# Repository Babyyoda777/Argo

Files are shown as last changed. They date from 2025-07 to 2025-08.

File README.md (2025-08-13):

# Argo









## Mainboard
The main board houses the CM5 and breaks out the most basic functionality needed.

- 2x 100pin Hirose Connectors
- 2x MIPI-DSI/CSI
- 1x Micro-HDMI
- 1x HDMI FPC connector for external break out
- 1x PCIe FPC connector, Pi 5 compatible
- 2x USB-C (One for power/flashing - USB 2.0 and one regular USB 3.0)
- Integrated BMS (BQ25895) with up to 15W output dependent on battery used.
- I2C control for BQ25895

Read more about the mainboard [here](./mainboard.md)

## Expansion Boards:

### M.2 PCIe Expansion:
- Adds an M.2 M-Key Slot for external SSD
Read more about the SSD board [here](./ssdboard.md)

### Impedance Calculations:



### OSHWA Certification:

PNG image

## Sponsored by OSHWLab Stars and HackClub:
 &nbsp;

 &nbsp;
  &nbsp;
   &nbsp;

 &nbsp;
  &nbsp;
   &nbsp;


Huge thanks to Bob from OSHWLab for all the support and sponsoring the PCBA! If you're a teenager interested in tech, checkout [HackClub](https://hackclub.com), huge thanks to them for covering remaining tools/materials costs.

### BOM:

| Part | Quantity | Price |
|---|---|---|
| Mainboard PCBA | 5 | $0.00  Paid Myself |
| SSD PCBA | 3 | $0.00 Paid myself funds redirected to soldering iron + batteries and jumper cables |
| Shipping + Taxes | 1 | $57.80 |
| [3.7V 3000mAh LiPo](https://www.aliexpress.com/item/1005006866132237.html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) | 1 | $25.00 |
| Thermal Pads | 1x | $8 |
| Raspberry Pi CM5 | | $120.00 |
| CM5 Cooler | 1 | $7.00 |
| PCIe FPC + Display FPC | 3 | $3.95 |
| Soldering iron + solder + microsoldering tips | 1 | $69 |
Note: Got sponsorship for PCB so price reduced to $61 from $350. 16GB CM5 needed due to the astro-stacking software and various other things that will be run in parallel.

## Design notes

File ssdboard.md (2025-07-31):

SSD Board in Argo footprint.
Support M.2 2230 and 2242 sizes NVMe SSDs. Based on offical CM5 M.2 HAT+

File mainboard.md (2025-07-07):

# Mainboard Specifications:

The mainboard is a 6 Layer 1.6mm PCB and uses the JLCPCB JLC06161H-3313 stackup. The layer distribution used is: [SIG/PWR : GND : SIG/PWR : PWR(5V) : GND : SIG/PWR]

## Layer 1 (Top):
Layer 1

## Layer 2:
Layer 2

## Layer 3:
Layer 3

## Layer 4:
Layer 4

## Layer 5:
Layer 5

## Layer 6 (Bottom):
Layer 6

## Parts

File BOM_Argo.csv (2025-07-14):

ID | Name | Designator | Footprint | Quantity | Manufacturer Part | Manufacturer | Supplier | Supplier Part
1 | CONN-SMD_DF40HC-3.0-100DS-0.4V-51 | CN1,CN2 | CONN-SMD_DF40HC-3.0-100DS-0.4V-51 | 2 | CONN-SMD_DF40HC-3.0-100DS-0.4V-51 | HRS(广濑) | LCSC | C424649
2 | GREEN | U14 | LED0603-FD | 1 | GREEN | YONGYUTAI(永裕泰) | LCSC | C19273151
3 | 1kΩ | R29,R34 | R0402 | 2 | 0402WGF1001TCE | UNI-ROYAL(厚声) | LCSC | C11702
4 | GT-TC018A-H0375-L1 | SW1 | SW-SMD_L4.7-W3.5-P3.35-EH | 1 | GT-TC018A-H0375-L1 | G-Switch(品赞) | LCSC | C963235
5 | 74LVC1G07SE-7 | U16 | SC-88A_L2.0-W1.3-P0.65-LS2.1-BL | 1 | 74LVC1G07SE-7 | DIODES(美台) | LCSC | C67531
6 | YLED0603R | LED1 | LED0603-FD | 1 | YLED0603R | YONGYUTAI(永裕泰) | LCSC | C19171390
7 | TS-1928-B | SW2 | KEY-SMD_4P-L2.8-W2.0-P1.20-LS3.0-TL | 1 | TS-1928-B | XKB Connectivity(中国星坤) | LCSC | C1121891
8 | BQ25895RTWR | U9 | QFN-24_L4.0-W4.0-P0.50-TL-EP2.7 | 1 | BQ25895RTWR | TI(德州仪器) | LCSC | C80200
9 | 2.2uH | L1 | IND-SMD_L6.5-W6.5_IHLP-2525 | 1 | IHLP2525CZER2R2M01 | VISHAY(威世) | LCSC | C540967
10 | 47nF | C4 | C0402 | 1 | CC0402KRX7R8BB473 | YAGEO(国巨) | LCSC | C107020
11 | 4.7uF | C3,C59 | C0603 | 2 | CL10A475KO8NNNC | SAMSUNG(三星) | LCSC | C19666
12 | 1uF | C1,C58 | C0805 | 2 | CL21B105KBFNNNE | SAMSUNG(三星) | LCSC | C28323
13 | 10kΩ | R13,R14,R15,R16,R26,R27,R28 | R0402 | 7 | 0402WGF1002TCE | UNI-ROYAL(厚声) | LCSC | C25744
14 | 10uF | C2,C5,C31,C51,C52 | C0805 | 5 | GRM21BR71A106KE51L | muRata(村田) | LCSC | C86038
15 | TYPEC-304J-BCP16 | PWR | USB-C-SMD_TYPEC-304J-BCP16 | 1 | TYPEC-304J-BCP16 | XUNPU(讯普) | LCSC | C2835315
16 | 5.1kΩ | R7,R6 | R0603 | 2 | 0603WAF5101T5E | UNI-ROYAL(厚声) | LCSC | C23186
17 | NSR10F20NXT5G | D1 | DSN-2_L1.4-W0.6-RD | 1 | NSR10F20NXT5G | onsemi(安森美) | LCSC | C893809
18 | 22uF | C55,C56,C57 | C0805 | 3 | CL21A226MAQNNNE | SAMSUNG(三星) | LCSC | C45783
19 | TLV70430DBVR | U13 | TSOT-23-5_L2.9-W1.6-P0.95-LS2.8-BR | 1 | TLV70430DBVR | TI(德州仪器) | LCSC | C133625
20 | BAT54C-7-F | D2 | SOT-23-3_L2.9-W1.6-P1.90-LS2.8-BR | 1 | BAT54C-7-F | DIODES(美台) | LCSC | C134405
21 | 5050060812 | CN5 | CONN-SMD_5050060810 | 1 | 5050060812 | MOLEX | LCSC | C779875
22 | FH12-22S-0.5SH(55) | DPHY1,DPHY2 | FPC-SMD_22P-P0.50_FH12-22S-0.5SH-55 | 2 | FH12-22S-0.5SH(55) | HRS(广濑) | LCSC | C597981
23 | 2.2kΩ | R30,R31,R32 | R0402 | 3 | 0402WGF2201TCE | UNI-ROYAL(厚声) | LCSC | C25879
24 | GT-F0509SR15-16SMT01 | PCIe | CONN-SMD_GT-F0509SR15-16SMT01 | 1 | GT-F0509SR15-16SMT01 | G-Switch(品赞) | LCSC | C21882325
25 | RT9742GGJ5 | U7,U11 | TSOT-23-5_L2.9-W1.6-P0.95-LS2.8-BR | 2 | RT9742GGJ5 | RICHTEK(立锜) | LCSC | C250547
26 | 12kΩ | R12 | R0603 | 1 | 0603WAF1202T5E | UNI-ROYAL(厚声) | LCSC | C22790
27 | 10uF | C30 | C0805 | 1 | CL21A106KAYNNNE | SAMSUNG(三星) | LCSC | C15850
28 | 100nF | C40,C41,C62 | C0402 | 3 | CC0402KRX5R8BB104 | YAGEO(国巨) | LCSC | C106256
29 | HDMI-101W | HDMI1 | HDMI-SMD_HDMI-101W | 1 | HDMI-101W | XUNPU(讯普) | LCSC | C720619
30 | TF-123-ARP9H15 | SD-CARD | TF-SMD_TF-123-ARP9H15 | 1 | TF-123-ARP9H15 | XUNPU(讯普) | LCSC | C2982547
31 | HDGC0802WV-S-10P | SPI | CONN-SMD_10P-P0.80_HDGC0802WV-S-10P | 1 | HDGC0802WV-S-10P | HDGC(华德共创) | LCSC | C3008688
32 | BM04B-SRSS-TB(LF)(SN) | FAN,I2C | CONN-SMD_BM04B-SRSS-TB | 2 | BM04B-SRSS-TB(LF)(SN) | JST | LCSC | C160390
33 | TYPEC-324-BCP24 | USB-C3.0 | USB-C-SMD_TYPEC-324-BCP24 | 1 | TYPEC-324-BCP24 | XUNPU(讯普) | LCSC | C2835314
34 | HD3SS3212IRKSR | U18 | DHVQFN-20_L4.5-W2.5-P0.50-BL-EP | 1 | HD3SS3212IRKSR | TI(德州仪器) | LCSC | C544517
35 | 100nF | C60 | C0402 | 1 | CC0402KRX5R6BB104 | YAGEO(国巨) | LCSC | C129131
36 | TPD4E05U06QDQARQ1 | D6,D4,D5 | USON-10_L2.5-W1.0-P0.50-BL | 3 | TPD4E05U06QDQARQ1 | TI(德州仪器) | LCSC | C81353
37 | 4.7kΩ | R35 | R0402 | 1 | 0402WGJ0472TCE | UNI-ROYAL(厚声) | LCSC | C25940
38 | TUSB321RWBR | U19 | X2QFN-12_L1.6-W1.6-P0.40-TL | 1 | TUSB321RWBR | TI(德州仪器) | LCSC | C139392
39 | 910kΩ | R36 | R0603 | 1 | 0603WAF9103T5E | UNI-ROYAL(厚声) | LCSC | C23263
40 | AP22653W6-7 | U12 | SOT-23-6_L2.9-W1.6-P0.95-LS2.8-BR | 1 | AP22653W6-7 | DIODES(美台) | LCSC | C2158037
41 | 100uF | C53 | CASE-B_3528 | 1 | TAJB107K006RNJ | Kyocera AVX | LCSC | C16133
42 | 15kΩ | R25 | R0402 | 1 | 0402WGF1502TCE | UNI-ROYAL(厚声) | LCSC | C25756
43 | CM5IO_ComputeModule5-CM5 | MODULE1 | CM5IO:Raspberry-Pi-5-Compute-Module | 1

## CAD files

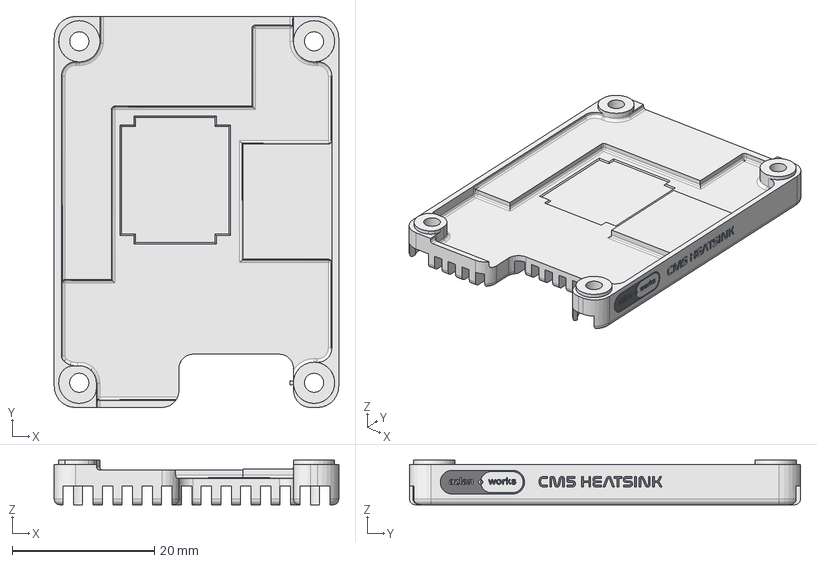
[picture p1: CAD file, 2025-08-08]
Argo CM5 Heatsink.step
40.0 x 55.0 x 6.27 mm

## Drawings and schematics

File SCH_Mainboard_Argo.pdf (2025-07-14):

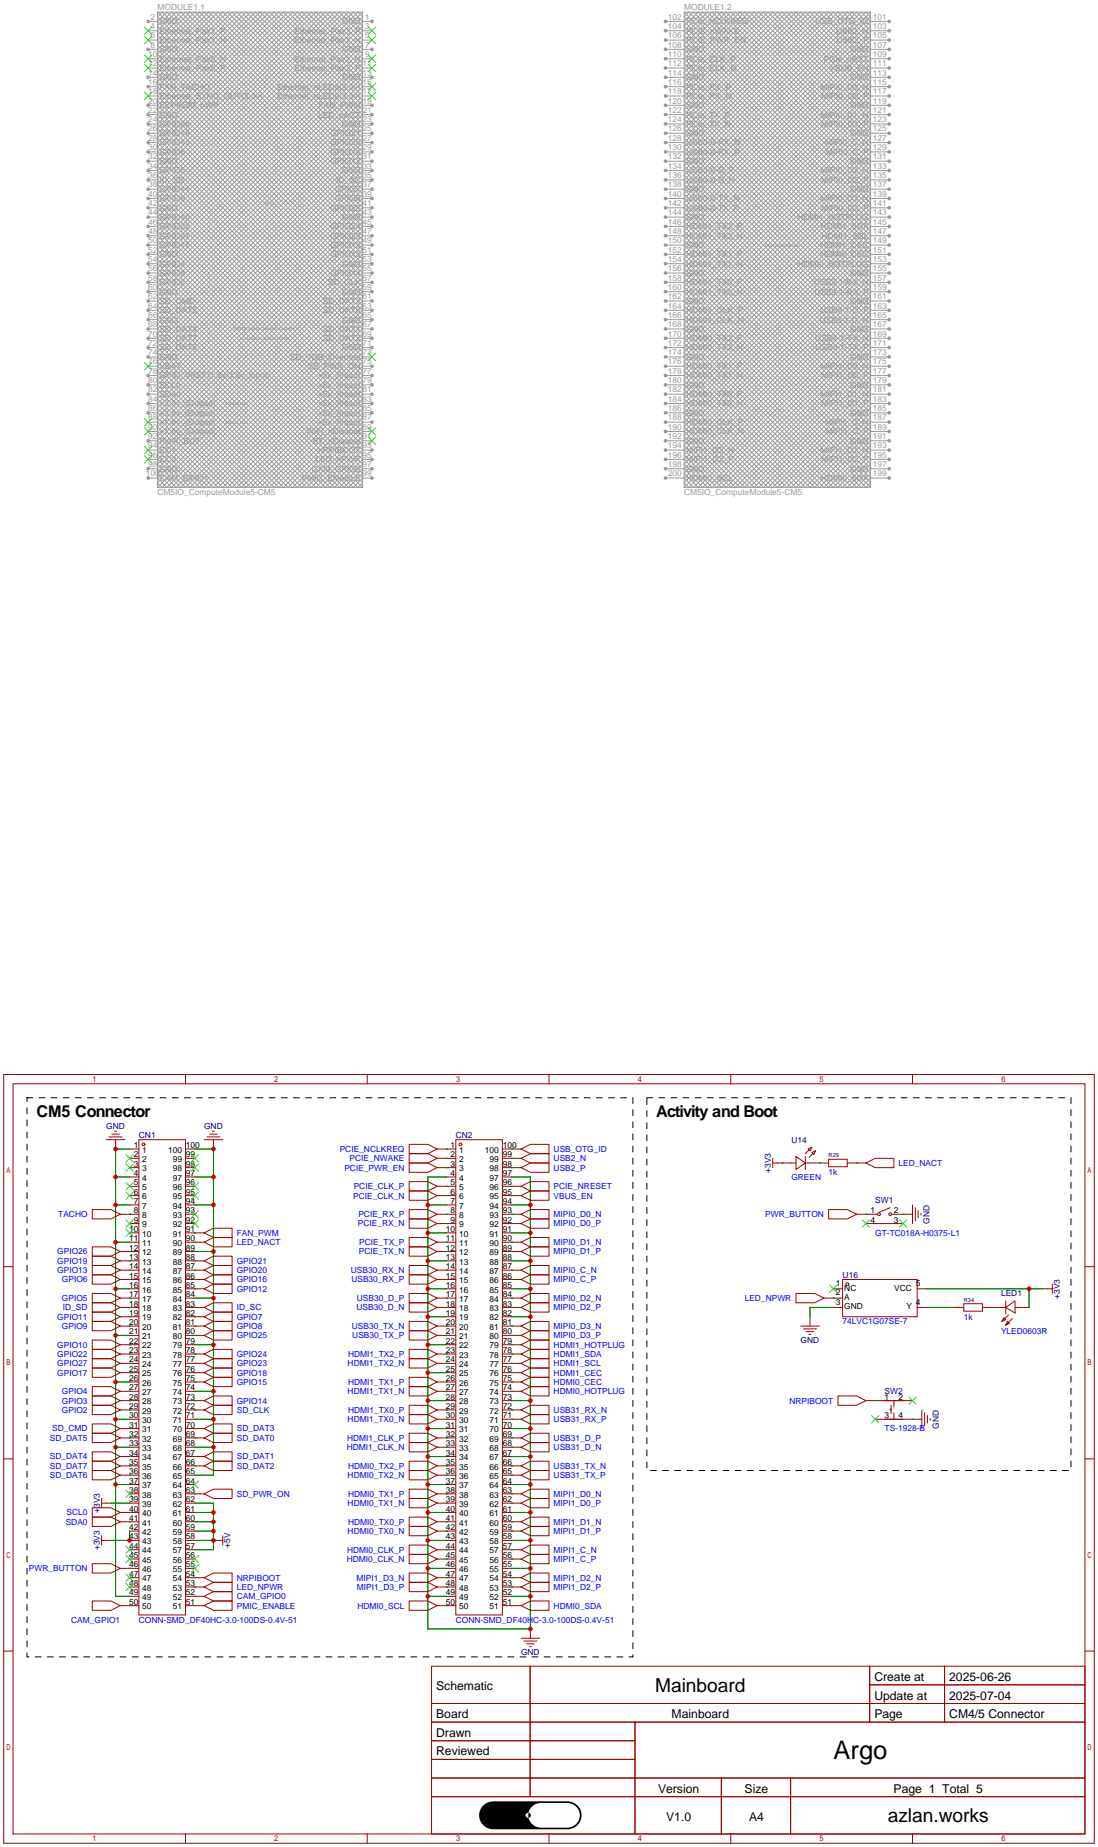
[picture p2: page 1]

NB SD signals are only available
on modules without eMMC

Schematic | Mainboard | Create at | 2025-06-26

Update at | 2025-07-04

Board | Mainboard | Page | CM4/5 Connector
Drawn | | Argo
Reviewed

Version | Size | Page 1 Total 5
V1.0 | A4 | azlan.works

# BQ25895 Charger

# 5.1k GND A¹B¹² VBUS A⁴B⁹ CC¹ A⁵

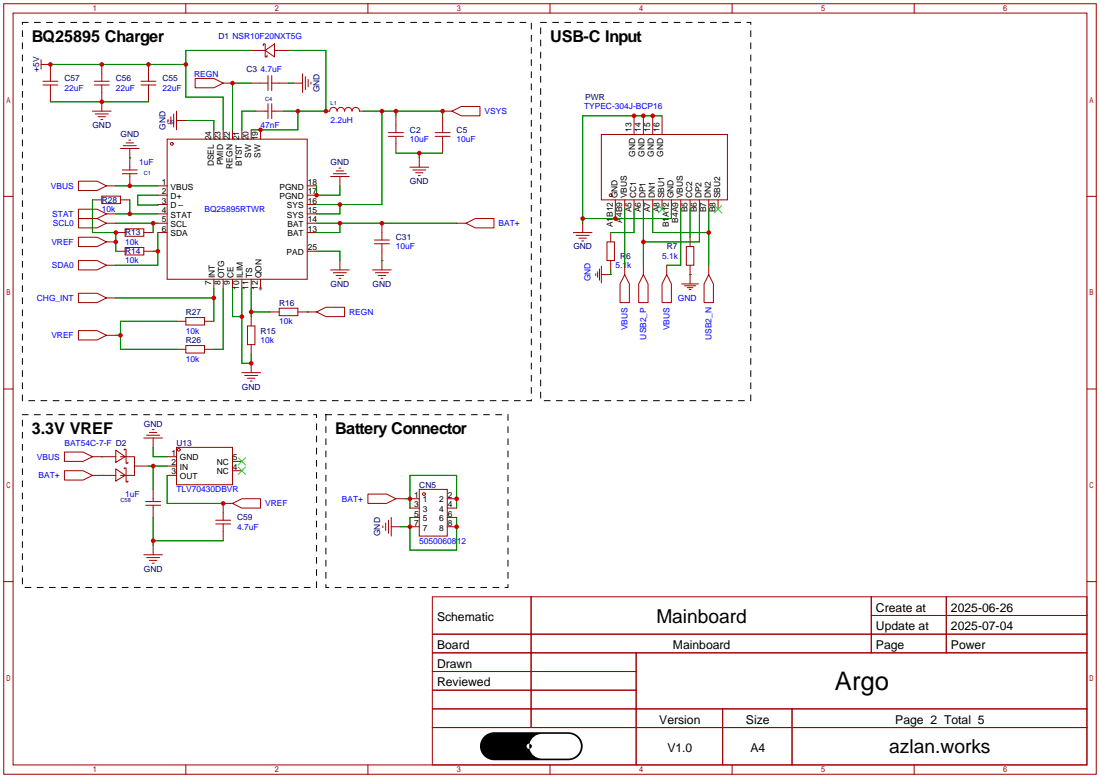
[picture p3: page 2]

BAT 13 BAT 14 SYS 15 SYS 16 PGND 17 PGND 18

Schematic | Mainboard | Create at | 2025-06-26

Update at | 2025-07-04

Board | Mainboard | Page | Power
Drawn | | Argo
Reviewed

# DPHY1

# PCIe

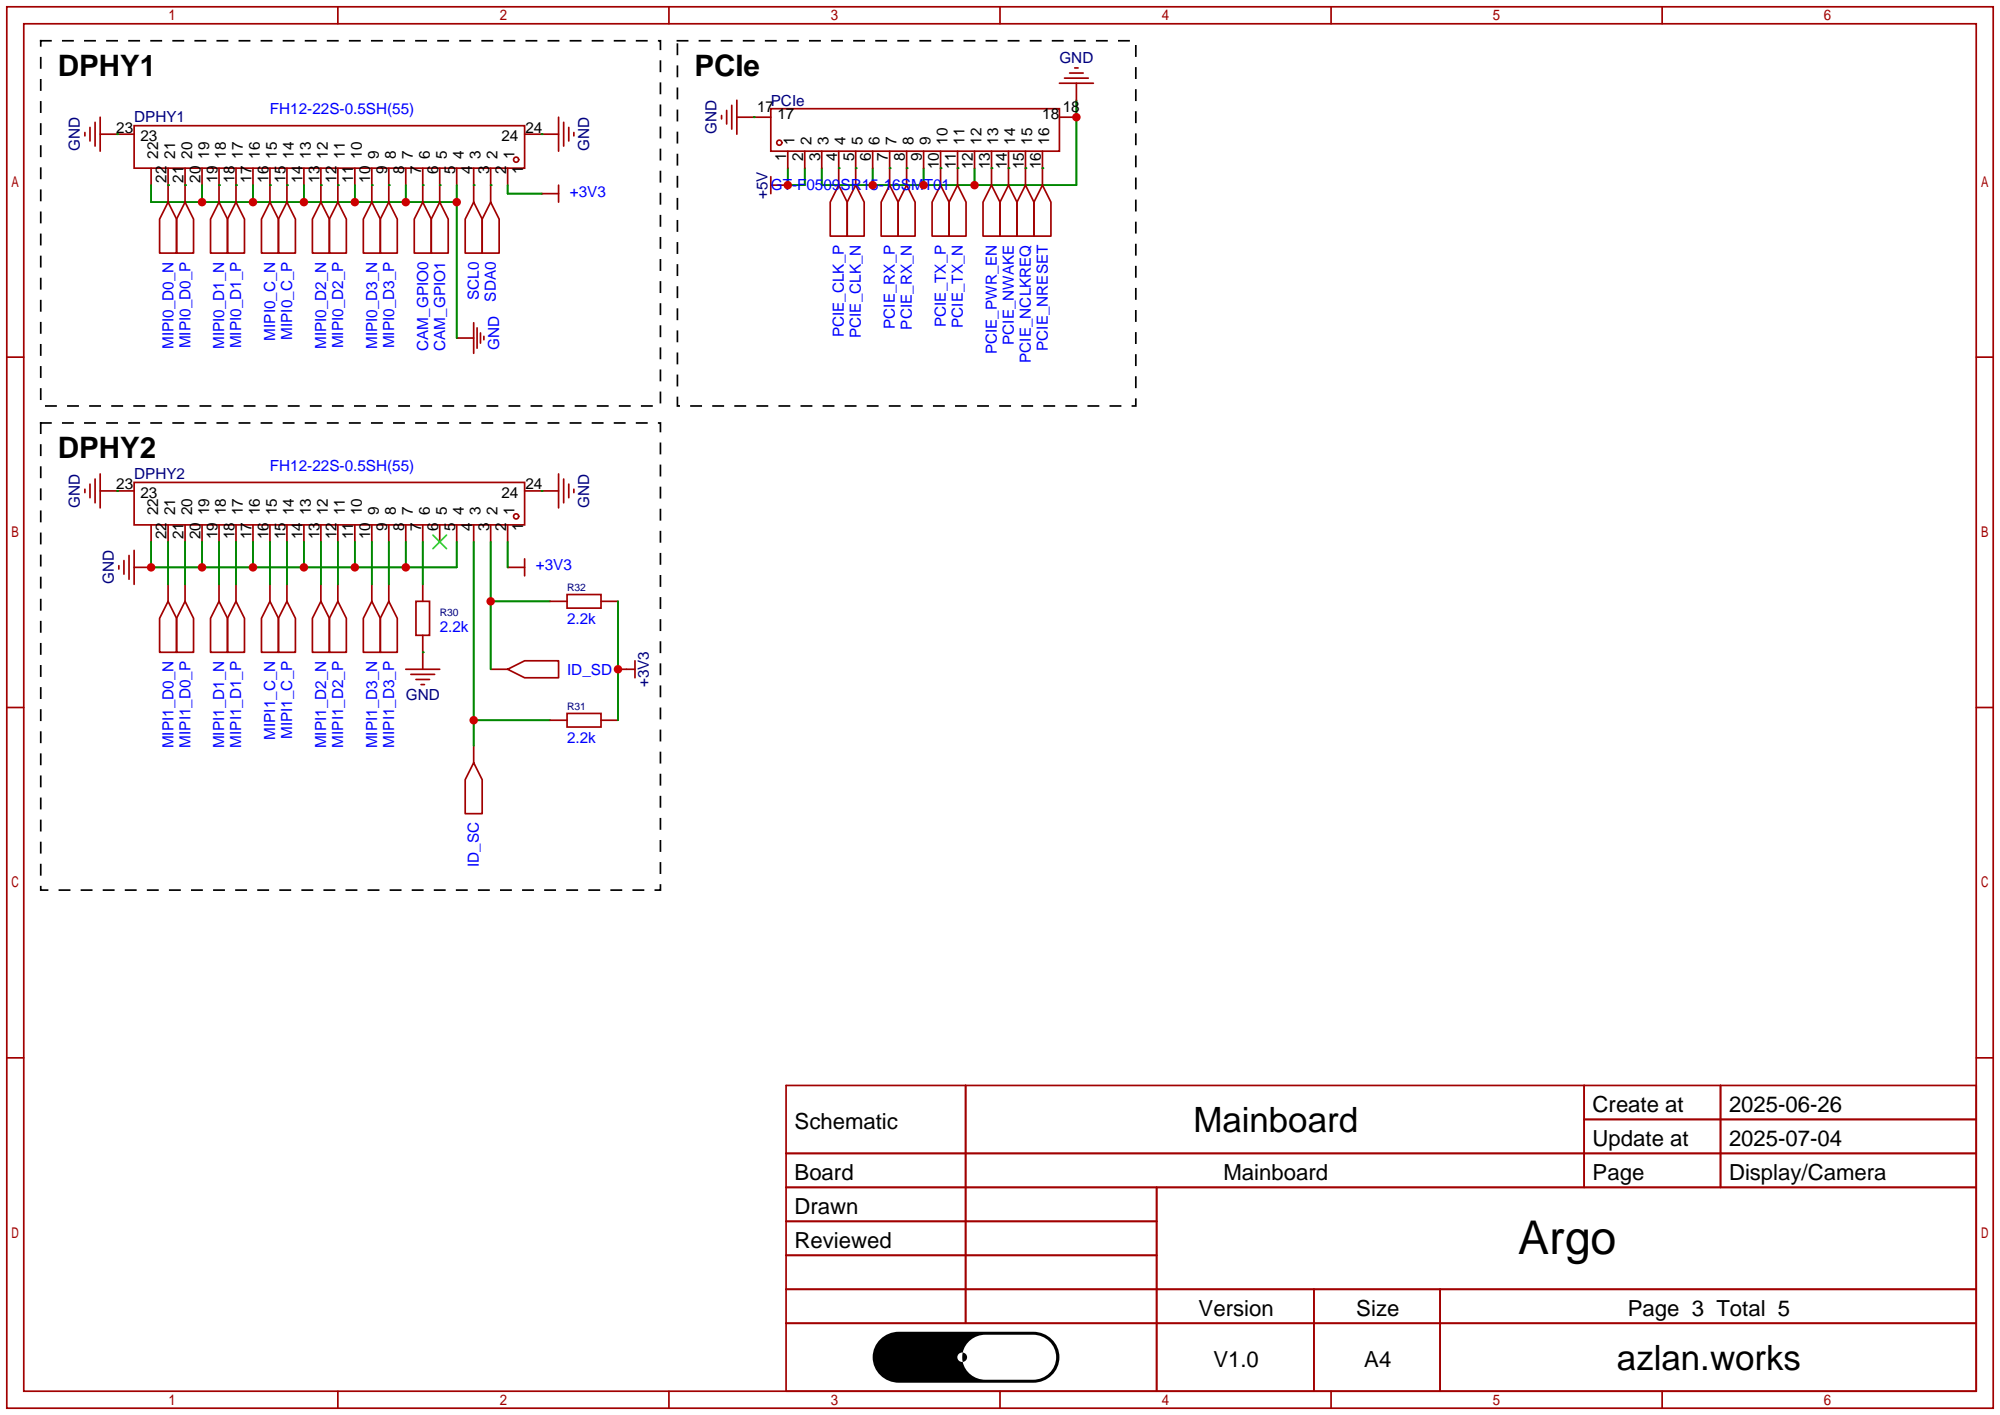
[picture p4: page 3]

Schematic | Mainboard | Create at | 2025-06-26

Update at | 2025-07-04

Board | Mainboard | Page | Display/Camera
Drawn | | Argo
Reviewed

# GND TACHO

# HDMI

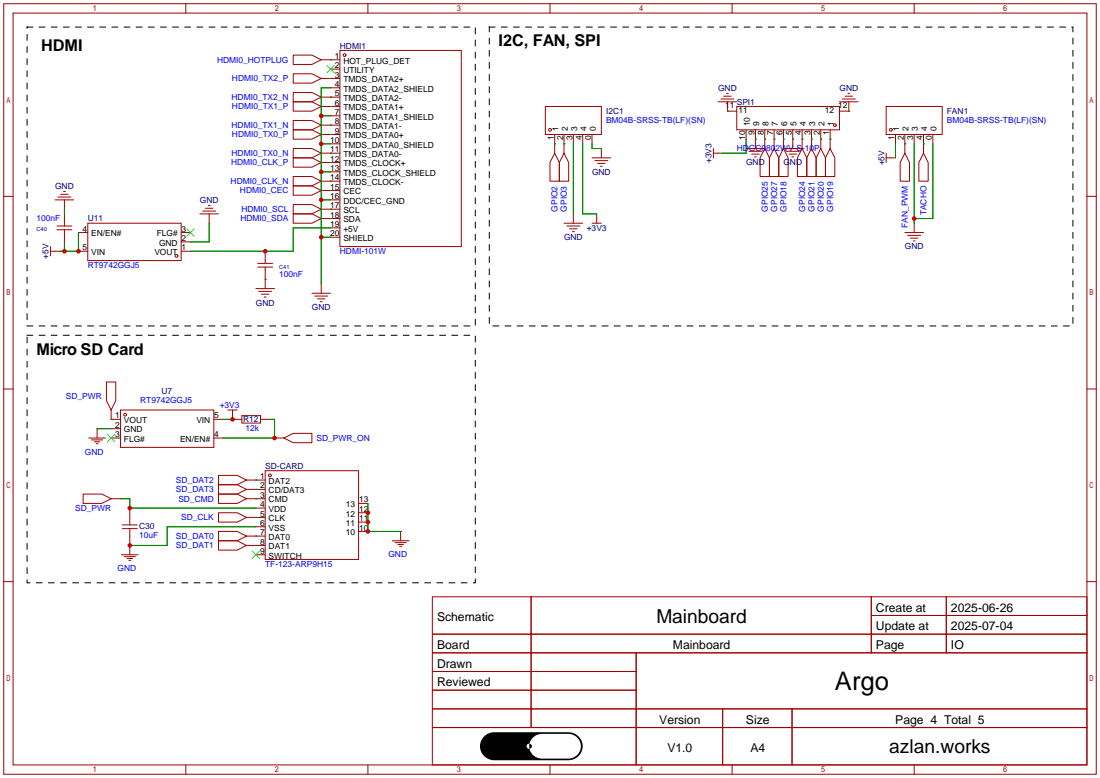
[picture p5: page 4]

BM04B-SRSS-TB(LF)(SN)

FAN1

Schematic | Mainboard | Create at | 2025-06-26

Update at | 2025-07-04

Board | Mainboard | Page | IO
Drawn | | Argo
Reviewed

## GNDGND

USB 3.0 SS Mux | USB-C Orientation Detection

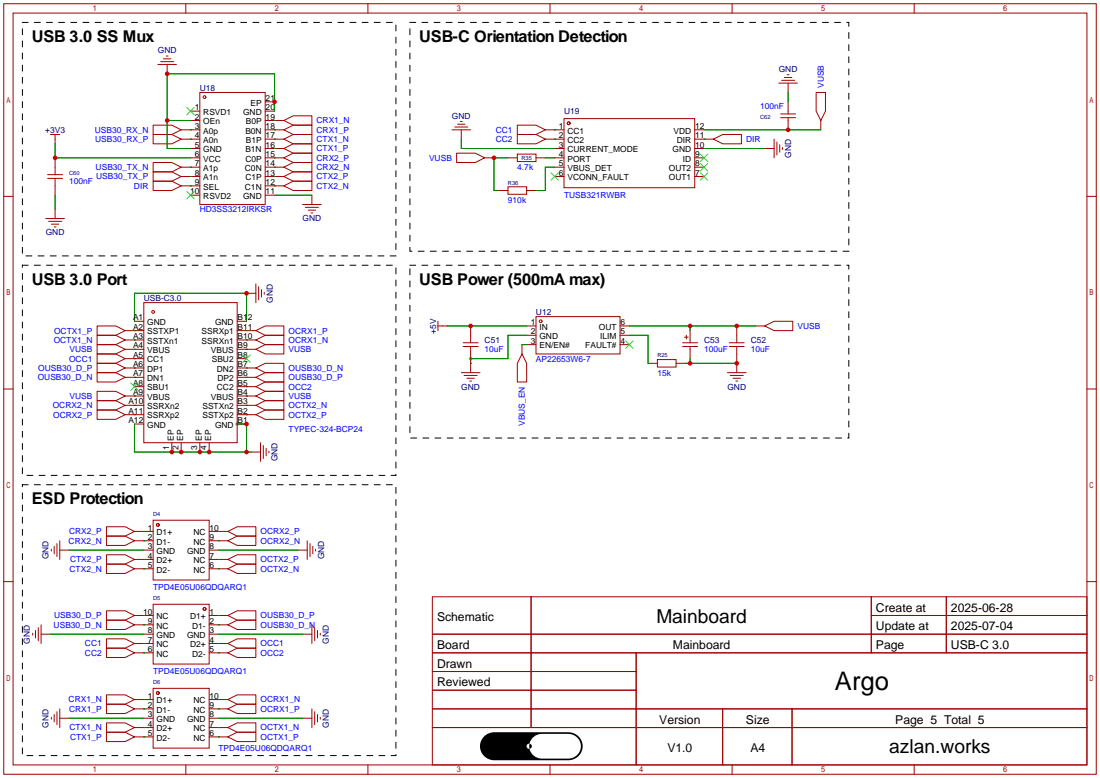
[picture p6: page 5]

Schematic | Mainboard | Create at | 2025-06-28

Update at | 2025-07-04

Board | Mainboard | Page | USB-C 3.0
Drawn | | Argo
Reviewed

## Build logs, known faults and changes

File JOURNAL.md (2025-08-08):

---
title: Icarus
author: Muhammad Azlan Shah
description: Opensource battery powered CM5 carrier board.
created_at: "2025-06-25"
total time spent: 62 hours
---

# June 20th:

Initial Roadmapping, component selection and formfactor decisions.



Decided on formfactor similar to Waveshare Nano series due to nice compact formfactor.

Time Spent: 3 hours

# June 22nd:

Exploring TPS61088 based boost converter system for fixed 5V battery power:



Runs in conjuction with loadsharing battery charging IC. Main idea is that most TI battery chargers have an internal fet that can pass through around 6A of continuous discharging current from the battery. This means, boosted to 5V, you can generally get 4-5A so around meeting the Pi 5 requirements but depending on how charged the battery is. This exceeds the usual 5V 3A limit that the integrated OTG boost that some chargers support can provide. Still need to consider whether this is actually worth it as the TPS61088 takes a large amount of board space.



Time Spent: 5 hours

# June 24th

Scrapped TPS61088, most LiPos can't safely discharge more than 3-5A unless its a 18650 or similar at 1S so its ideal to use built in boost converter of BQ25895 for up to 5V @ 3.1A for the CM5. This comes off the back of the CM5 datasheet power requirements section which states that during normal operation it uses 900mA. Additional testing from Jeff Geerling shows the absolute max power draw (when under stress) by an overcloked CM5 was around 8W. This leaves around 7.5W for remaining functions which fits almost perfectly with the 2.5W output for the USB port and 5W needed for rhe PCIe connection. Thanks Jeff!



Completed schematic above.

Time spent: 3 days

# June 30th:

Began layout after completing remaining schematics based on CM5 IO Board schematics for basic functionality.

Using a 4 Layer stack up as SIG/PWR : GND : GND : SIG/PWR





Four layers helps with heat dissipation. I learnt the hard way how hot a charging IC can get on a 2 Layer board without oodles of space on the ground pour for heat dissipation, the extra copper really helps and makes it more suitable for stacking batteries close to the board. After all, batteries really dont like heat...

Time spent: 8 hours

# July 3rd:

Turns out 4 layers will not be sufficient due to small board size and power routing. Moving to 6 layer stack up as SIG/PWR : GND : SIG/PWR : PWR : GND : SIG/PWR

Got sanity check on TI Forum for BQ25895 layout and schematic for more confidence.



Time Spent: 16 hours (complete rerouting needed).

# July 4th:

Further look into USB-C and USB 3.0 turns out to get CM5 to have a USB-C 3.0 port rather than a simple USB-A 3.0 port you need and SS Mux to manage the reversible connector and its need for double the RX and TX superspeed lines. Luckily the regular USB 2.0 D+ and D- lines don't really need anything as the traces are relatively shot so redriver is optional and its probably ok.



Time spent: 4 hours

# July 5th:

Worked on finding a suitable small battery connector. Decided to use a Molex backplane connector as it can handle up to 6A which is around 24W max and 18W minimum if pushing full 6A through so should be more than enough to handle CM5 with a high discharge LiPo/Li-ion.



Time spent: 2 hours

# July 6th:

Rerouted HDMI differential pairs for slightly cleaner look. Also increased trace width for power supply to micro-HDMI port just to be safe: 



Time spent: 1 hour

# July 7th:

Worked on breaking out som GPIO as dedicated I2C and SPI lines. Also added connector for CM5 fan as these things can run hot and thermal throttle:



Time spent: 1 hour

# July 8th:

Redid layout for BQ25895 again. Focus on minimising overheating and some concern for EMI. Considered using resistor array for 10k resistors however its more expensive to use an array and functionally not significant so left as is. New routing:



Time spent: 2 hours

# August 4th:

Sent for production but had issue spotted on PCB. Turns out length matching on inner layer was a bit too close so was at risk of short circuit. Got it fixed so should be good to go!



Time spent: 1 hour

# August 5th:

Started work on SSD add-on. This board is a miniaturised version of the official M.2 HAT+ but with minor changes to work purely off the PCIe flex cable without requiring external 5V. As such it consumes a max of 5W but also means the SSD being used will need to be low power. 



From above, the board also uses a much thinner profile M.2 Connector and screw mounts, as such only single sided M.2 NVMe SSDs will work. Whilst double sided ones will work, it may be difficult to get them flush to the board but that awaits testing.

The reason for this choice is to allow for a battery to be stacking underneath this board. Together with the main board, the total dimensions from a bird's eye view is 85mm x 55mm which includes a 5mm gap between the two, which will be used for routing of PCIe FPC cable.

IMPORTANT NOTE: The FPC connectors used are both double sided contacts, this is to allow flexibility of board placement and also which FPC cable is used.

Time spent: 3 hours

# August 6th:

Ordered first PCB prototype (my bank account hurts). Thanks to Bob from OSHWLab for sponsoring! Cost of 5 main boards with expidited assembly and fabrication was $350. Regular slow manufacturing wouldve probably been half the price :/ but i had very little time to get the board in my hands to test.



# August 8th:

Designed a custom low-profile heatsink for the CM5, will likely be manufactured at JLCCNC. This heatsink features close-to direct metal contact with hottest parts of CM5, including the main SoC as well as power delivery chips. Also added my own little design spin :)
